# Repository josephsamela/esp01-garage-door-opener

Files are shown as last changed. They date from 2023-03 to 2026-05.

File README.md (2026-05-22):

# esp01-garage-door-opener

esp01 IoT device to open/close your garage door with Apple HomeKit



## Software

This device can be controlled completely independent of any smart-home infastructure. It's simply an IoT "thing" you send HTTP GET requests to open/close your garage door.

That said, I personally am integrating this with Apple HomeKit. In order to do this you'll need a local instance of [Homebridge](https://homebridge.io/). You'll also need to install the [homebridge-http-garage](https://github.com/phenotypic/homebridge-http-garage) plugin for homebridge.

Once connected to your network, set a DHCP reservation so the device retains it's IP address. Then you can control it by sending HTTP requests to the routes below:

### Routes

The `/` endpoint is purely informational. It's helpful when setting up the garage door the first time.
```
/
```

The `/toggle` endpoint toggles the garage door. It's equivelant to you pushing the garage door button.

```
/toggle
```

The `status` endpoint will return json indicating the state of the garage door. `{"currentState":0}`
```
/status
```

The `setState` route accepts a query param called `value`. You can set state to `0` (open) or `1` (closed).
```
/setState?value=INT_VALUE
```
### Homebridge

[homebridge-http-garage](https://github.com/phenotypic/homebridge-http-garage)

```json
{
    "accessory": "GarageDoorOpener",
    "name": "Garage Door",
    "apiroute": "http://192.168.1.35",
    "openTime": 15,
    "closeTime": 15,
    "autoLock": false,
    "autoLockDelay": 20,
    "pollInterval": 15,
    "timeout": 5000,
    "http_method": "GET"
}
```

### Home Assistant

```yaml
 switch:
   - platform: rest
     name: garage_door
     unique_id: garage_door
     resource: http://192.168.1.35/setState
     state_resource: http://192.168.1.35/status
     is_on_template: '{{ value_json.currentState == 0 }}'
     params:
       value: >
         {% if is_state('switch.garage_door', 'on') %}
           1
         {% else %}
           0
         {% endif %}

 cover:
   - platform: template
     covers:
        garage_door:
         friendly_name: "Garage Door"
         device_class: "garage"
         value_template: "{{ is_state('switch.garage_door', 'on') }}"
         open_cover:
           service: switch.turn_on
           target:
             entity_id: switch.garage_door
         close_cover:
           service: switch.turn_off
           target:
             entity_id: switch.garage_door
```

## Hardware

The hardware is an ESP-01 microcontroller with a relay module. The rear of the garage door unit has three screw terminals connected to the wall switch. The relay is connected between the two screw terminals connected to the garage door opener push-button. When the relay is closed the garage door unit recognizes this as a "button press" and opens/closes the door as if you pushed the button on the wall.

- [ESP-01 and Relay Board](https://www.aliexpress.us/item/2251832647269116.html) ~$2
- [Wired door sensor](aliexpress.us/item/2255800949489160.html) ~$1
- 10k Ohm Resistor. <$0.01
- 5V USB Charger (I used a spare phone charger)

## Installation

First wire the switch to the relay board with pull-down resistor. Then Wire the relay to garage door terminals as shown.



| ESP01 | Relay | Garage Door | Switch |
|:-----:|:-----:|:---:|:---:|
|  3.3V |  VCC  | | |
|  GND  |  GND  | |  GND |
|  D0 | IN  | | |
| | NC  | Switch 1  | |
| | C | Switch 2  | |
|  D3 | | |  POS |

The GPIO pin `D3` is used for the wired door switch. The resistor is a pull-down resistor that you need to wire between `D3` to `GND`. I chose to solder the resistor to the bottom of the relay board.

## Hardware Mounting

To mount switch and to garage door components, I designed several parts in the `./switch-mount` folder. Both sides of the switch are screwed to the brackets. Then the brackets are pressed onto edge of the garage door track.

For the switch relay I printed [this case](https://www.thingiverse.com/thing:3976187) which has an easy to remove top.

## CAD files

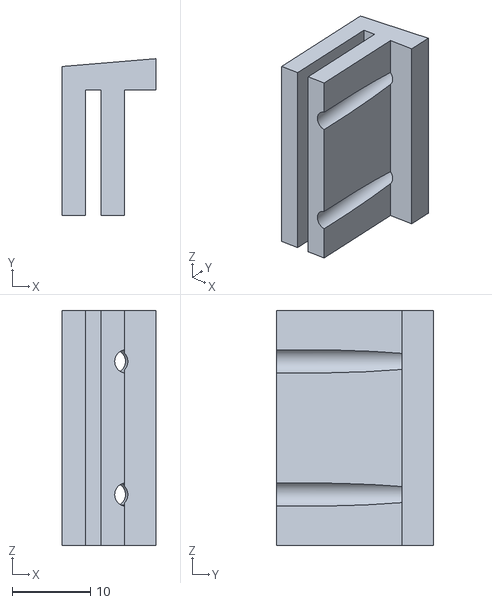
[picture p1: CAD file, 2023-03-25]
switch-mount/garage-door-sensor-bracket-runner-Body.stl
12.0 x 20.0 x 30.0

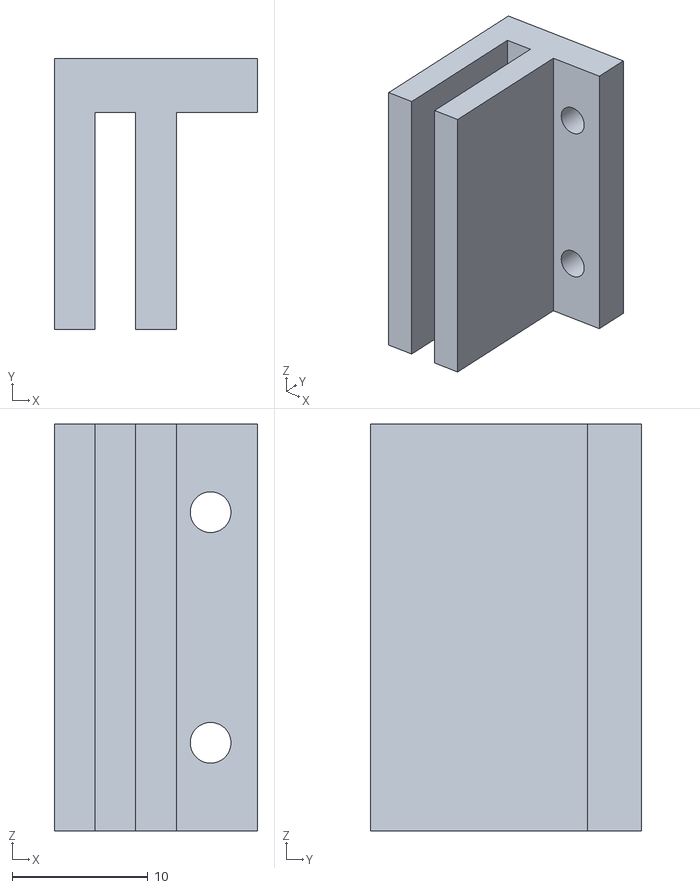
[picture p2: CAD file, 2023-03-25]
switch-mount/garage-door-sensor-bracket-stationary-Body.stl
15.0 x 20.0 x 30.0

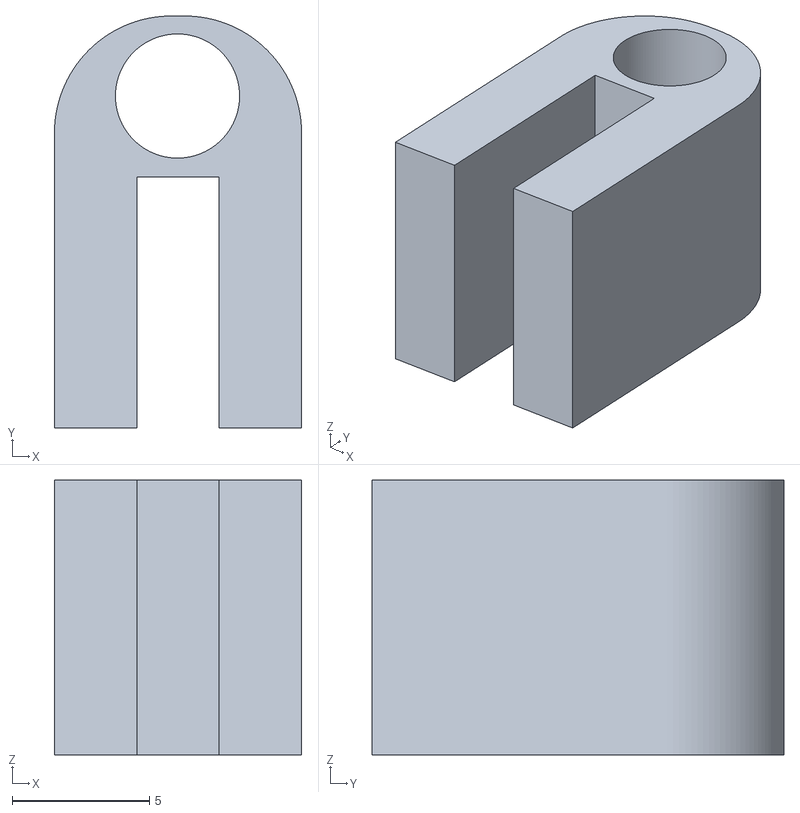
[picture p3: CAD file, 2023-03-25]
switch-mount/garage-door-sensor-bracket-wire-guide-Body.stl
9.00 x 15.0 x 10.0

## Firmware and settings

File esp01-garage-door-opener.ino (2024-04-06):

#include <ESP8266WiFi.h>
#include <WiFiClient.h>
#include <ESP8266WebServer.h>
#include <ESP8266mDNS.h>

const String ssid = "< SSID >";
const String password = "< PASSWORD >";
const String token = "< TOKEN >";

ESP8266WebServer server(80);

const int led    = 2;
const int sensor = 3;
const int relay  = 0;
const int lockDuration = 14000; //default 14 second lockout

int requestedState = 1; // open=0, closed=1
int currentState = 1; // open=0, closed=1
int lockExpire = 0; 

void setup() {
  // Initialize Serial
  Serial.begin(115200);
     
  // Connect to WiFi network
  Serial.println();
  Serial.print("Connecting to ");
  Serial.println(ssid);
 
  // Connect to wifi
  WiFi.mode(WIFI_STA);
  WiFi.begin(ssid, password);
  WiFi.setSleep(false);
  
  // Wait for connection
  while (WiFi.status() != WL_CONNECTED) {
    delay(500);
    Serial.print(".");
  }
  Serial.print("Connected to ");
  Serial.println(ssid);
  Serial.print("IP address: ");
  Serial.println(WiFi.localIP());
  if (MDNS.begin("esp8266")) {
    Serial.println("MDNS responder started");
  }

  // Setup GPIO pin modes
  pinMode(led, OUTPUT);
  pinMode(relay, OUTPUT);
  pinMode(sensor, INPUT);
  // Initialize GPIO positions
  digitalWrite(led, HIGH);
  digitalWrite(relay, HIGH);

  server.on("/", []() {
    server.send(200, "text/plain", "This is Joe's Garage Door!\nSend a GET request to an endpoint below: \n\n`/<token>/toggle`\t\tToggle door state. Digital 'press' of the garage door button.\n`/<token>/status`\t\tGet JSON status of garage door.\n`/<token>/setState?value=1`\tSet state of garage door. Valid states are the two values, `open=0` and `closed=1`\n");
  });
  
  server.on("/"+token+"/toggle", []() {
    digitalWrite(led, LOW);
    toggleGarageDoorState();
    server.send(200, "text/plain", "Pressed garage door button. Door state will toggle.\n");
    digitalWrite(led, HIGH);
  });

  server.on("/"+token+"/status", []() {
    digitalWrite(led, LOW);
    server.send(200, "text/plain", "{\"currentState\":" + String(currentState) + ",\"requestedState\":" + String(requestedState) +"}\n");
    digitalWrite(led, HIGH);
  });

  server.on("/"+token+"/setState", []() {
    String argValue = server.arg("value");
    requestedState = argValue.toInt();
    if (requestedState != currentState) {
      if (millis() >= lockExpire) {
        toggleGarageDoorState();
        lockExpire = millis() + lockDuration;
      }
    }
          server.send(200, "text/plain", "{\"currentState\":" + String(currentState) + ",\"requestedState\":" + String(requestedState) +"}\n");
          server.send(200, "text/plain", "{\"currentState\":" + String(currentState) + ",\"requestedState\":" + String(requestedState) +"}\n");
      }
    }
    server.send(200, "text/plain", "{\"currentState\":" + String(currentState) + ",\"requestedState\":" + String(requestedState) +"}\n");
      }
    }
  });

  server.onNotFound([]() {
    digitalWrite(led, 1);
    String message = "Route Not Found\n";
    message += "URI: ";
    message += server.uri();
    message += "\nMethod: ";
    message += (server.method() == HTTP_GET) ? "GET" : "POST";
    message += "\nArguments: ";
    message += server.args();
    message += "\n";
    for (uint8_t i = 0; i < server.args(); i++) {
      message += " " + server.argName(i) + ": " + server.arg(i) + "\n";
    }
    server.send(404, "text/plain", message);
  });

  server.begin();
  Serial.println("HTTP server started");

}

void toggleGarageDoorState() {
    digitalWrite(led, LOW);
    digitalWrite(relay, HIGH);
    delay(100);
    digitalWrite(relay, LOW);
    delay(100);
    digitalWrite(relay, HIGH);
    digitalWrite(led, HIGH);
}
 
void loop() { 
  currentState = digitalRead(sensor) ^ 1; // The XOR operator inverts the value read by the sensor.
  server.handleClient();
  MDNS.update();
  delay(2); //allow the cpu to switch to other tasks
}
